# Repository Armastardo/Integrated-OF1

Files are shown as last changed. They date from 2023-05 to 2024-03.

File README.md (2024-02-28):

# Integrated-OF1
RaspberryPi Pico-powered board compatible with Rev 1 Heavy and Rev 1/2 Light cases (to be sold in waves on the Frame1.gg website).
  
<p align="center">
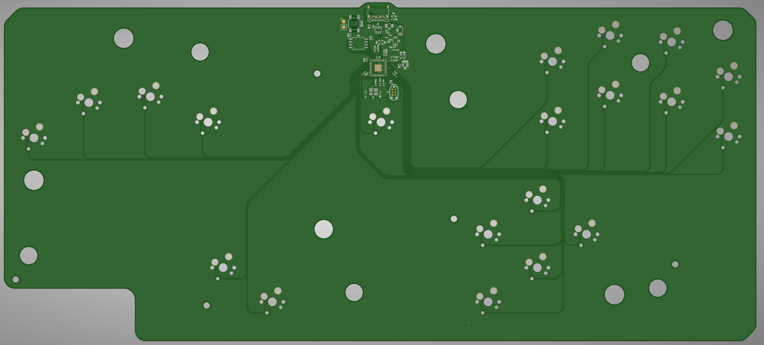
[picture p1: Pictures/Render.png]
  
</p>

Design files are available in this repository. Production files for JLCPCB in the releases page. Tested working and fitting previously mentioned Frame 1 cases.

## Table of contents
* [Features](#features)
* [Usage](#usage)
* [Acknowledgements](#acknowledgements)

## Features
- USB-C to GCC and USB-C to N64 cable compatible with integrated port.
- Uses [HayBox](https://github.com/JonnyHaystack/HayBox) and [Pico Rectangle](https://github.com/JulienBernard3383279/pico-rectangle) default pinout.

## Usage
1. Order via JLCPCB using the production files in the releases page.
2. Connect them to the PC and the first time it'll show up as a mass storage device.
3. Drop your prefered firmware in uf2 format and once it disconnects it should be good to go.
	- If you connect while pressing the BOOT button (or shorting the pads in the back), it'll show again as a mass storage device so you can update the firmware or replace it.
	- You can also press START on connect if using HayBox or CRIGHT if using pico-rectangle.

## Acknowledgements:
- Greg Turbo: For creating the Frame1 and the Open Frame 1.
- Crane's Lab discord server: For the community that inspired me to create things like this.

### Made using the Open Rectangle Template
OpenRectangleTemplate project - https://github.com/Armastardo/OpenRectangleTemplate

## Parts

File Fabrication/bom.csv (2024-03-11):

Designator | Footprint | Quantity | Value | LCSC Part #
C1, C10, C2, C4 | 0402 | 4 | 1uF | C52923
C11, C12, C13, C14, C15, C16, C17, C3, C5, C6 | 0402 | 10 | 100nF | C1525
C7, C8 | 0402 | 2 | 22pF | C1555
C9 | 0402 | 1 | 10uF | C15525
D1, D2 | D_SOD-123 | 2 | Schottky Diode | C8598
D3 | 0805 | 1 | GREEN | C2297
F1 | 1206 | 1 | 500 mA | C2836286
J1 | TYPE-C_24P_QCHT | 1 | USB C Connector | C456013
MX1, MX11, MX13, MX16, MX18, MX20, MX22, MX24, MX25, MX27, MX3, MX30, MX31, MX34, MX35, MX37, MX40, MX6, MX7, MX9 | SW_MX_HS_1u | 20 | MX_SW_HS
R1 | 0603 | 1 | 1M | C22935
R10, R11 | 0402 | 2 | 1k | C11702
R2, R3 | 0402 | 2 | 5.1k | C25905
R4 | 0402 | 1 | 470 | C25117
R5 | 0603 | 1 | 5.6k | C23189
R6 | 0603 | 1 | 10k | C25804
R7 | 0402 | 1 | 10k | C25744
R8, R9 | 0603 | 2 | 27 | C25190
SW1 | SW_SPST_SKQG_WithStem | 1 | Boot | C318884
U1 | SOT-23 | 1 | XC6206 | C5446
U2 | SOT-23-6 | 1 | USBLC6-2SC6 | C2827654
U3 | RP2040-QFN-56 | 1 | RP2040 | C2040
U4 | SOIC-8_5.23x5.23mm_P1.27mm | 1 | W25Q128JVS | C97521
Y1 | Crystal_SMD_3225-4Pin_3.2x2.5mm | 1 | 12MHz | C9002

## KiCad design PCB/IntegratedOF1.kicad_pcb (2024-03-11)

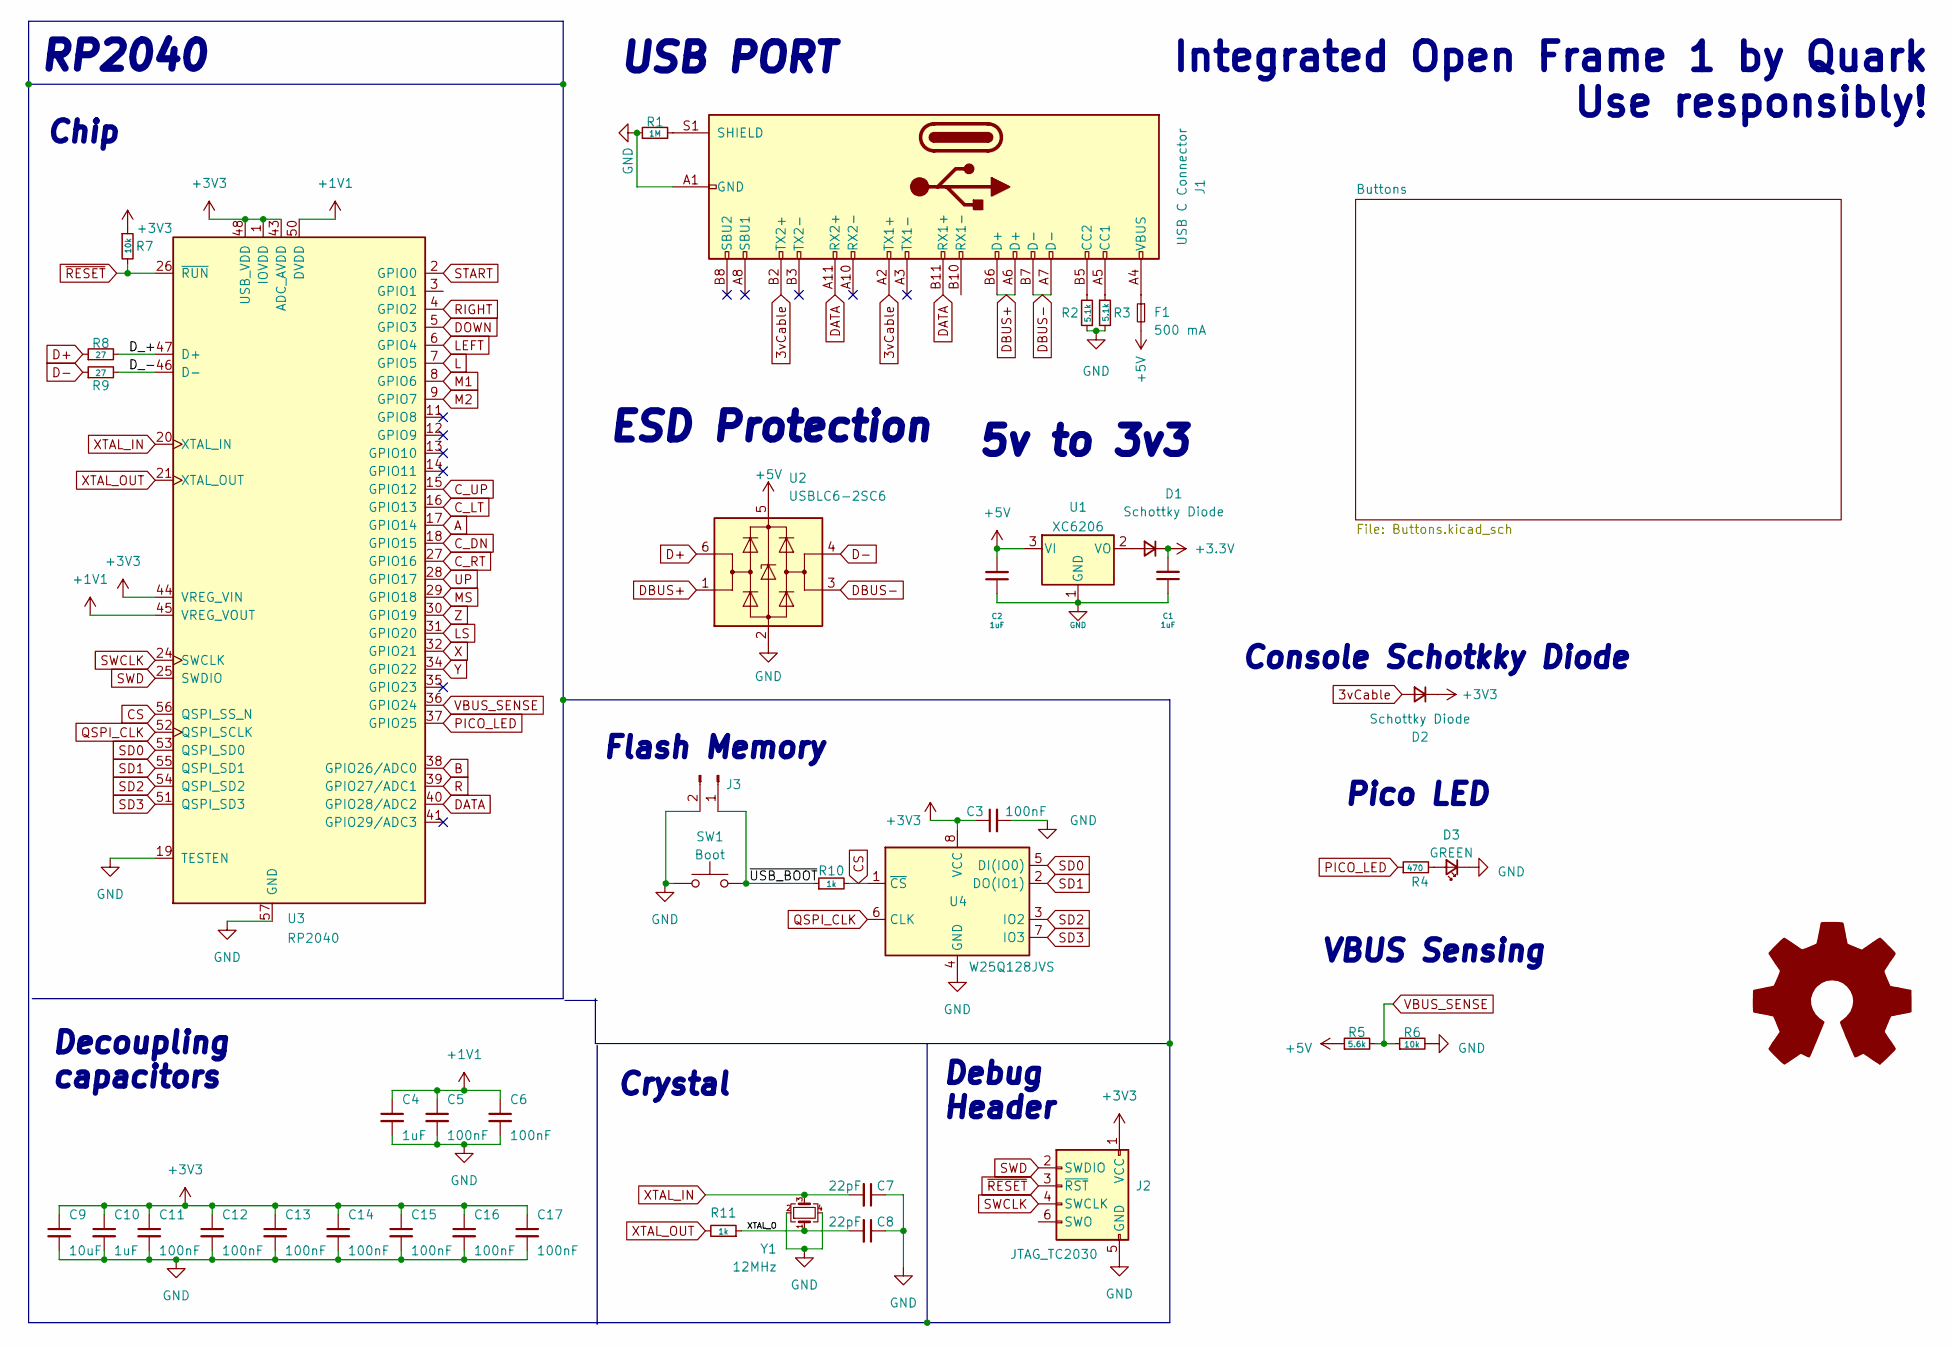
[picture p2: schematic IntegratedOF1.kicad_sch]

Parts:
C1, C2, C4, C10: 1uF; C_0402_1005Metric; LCSC C52923
C3, C5, C6, C11, C12, C13, C14, C15, C16, C17: 100nF; C_0402_1005Metric; LCSC C1525
C7, C8: 22pF; C_0402_1005Metric; LCSC C1555
C9: 10uF; C_0402_1005Metric; LCSC C15525
D1, D2: Schottky Diode; D_SOD-123; LCSC C8598
D3: GREEN; LED_0805_2012Metric; LCSC C2297
F1: 500 mA; Fuse_1206_3216Metric; LCSC C2836286
J1: USB C Connector; TYPE-C_24P_QCHT; LCSC C456013
J2: JTAG_TC2030; CON_TC2030_outlined
J3: Conn_01x02_Pin; PinHeader_1x02_P2.54mm_Vertical
R1: 1M; R_0603_1608Metric; LCSC C22935
R2, R3: 5.1k; R_0402_1005Metric; LCSC C25905
R4: 470; R_0402_1005Metric; LCSC C25117
R5: 5.6k; R_0603_1608Metric; LCSC C23189
R6: 10k; R_0603_1608Metric; LCSC C25804
R7: 10k; R_0402_1005Metric; LCSC C25744
R8, R9: 27; R_0603_1608Metric; LCSC C25190
R10, R11: 1k; R_0402_1005Metric; LCSC C11702
SW1: Boot; SW_SPST_SKQG_WithStem; LCSC C318884
SYM1: Logo_Open_Hardware_Large; OSHW-Logo_28.5x30mm_SilkScreen
U1: XC6206; SOT-23; LCSC C5446
U2: USBLC6-2SC6; SOT-23-6; LCSC C2827654
U3: RP2040; RP2040-QFN-56; LCSC C2040
U4: W25Q128JVS; SOIC-8_5.23x5.23mm_P1.27mm; LCSC C97521
Y1: 12MHz; Crystal_SMD_3225-4Pin_3.2x2.5mm; LCSC C9002

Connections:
3vCable: D2.2 (A), J1.A2 (TX1+), J1.B2 (TX2+)
+1V1: C4.1, C5.1, C6.1, U3.23 (DVDD), U3.45 (VREG_VOUT), U3.50 (DVDD)
+5V: C2.2, F1.2, R5.1, U1.3 (VI), U2.5 (VBUS)
/D_+: R8.2, U3.47 (D+)
/D_-: R9.2, U3.46 (D-)
/XTAL_O: C8.2, R11.1, Y1.1
/~USB_BOOT: J3.1, R10.1, SW1.2
A: U3.17 (GPIO14); also elsewhere on the board
B: U3.38 (GPIO26/ADC0); also elsewhere on the board
CS: R10.2, U3.56 (QSPI_SS_N), U4.1 (~CS)
C_DN: U3.18 (GPIO15); also elsewhere on the board
C_LT: U3.16 (GPIO13); also elsewhere on the board
C_RT: U3.27 (GPIO16); also elsewhere on the board
C_UP: U3.15 (GPIO12); also elsewhere on the board
D+: R8.1, U2.6 (I/O1)
D-: R9.1, U2.4 (I/O2)
DATA: J1.A11 (RX2+), J1.B11 (RX1+), U3.40 (GPIO28/ADC2)
DBUS+: J1.A6 (D+), J1.B6 (D+), U2.1 (I/O1)
DBUS-: J1.A7 (D-), J1.B7 (D-), U2.3 (I/O2)
DOWN: U3.5 (GPIO3); also elsewhere on the board
GND: C1.1, C2.1, C3.2, C4.2, C5.2, C6.2, C7.1, C8.1, C9.2, C10.2, C11.2, C12.2, C13.2, C14.2, C15.2, C16.2, C17.2, D3.1 (K), J1.A1 (GND), J1.A12 (GND), J1.B1 (GND), J1.B12 (GND), J2.5 (GND), J3.2, R1.1, R2.1, R3.2, R6.2, SW1.1, U1.1 (GND), U2.2 (GND), U3.19 (TESTEN), U3.57 (GND), U4.4 (GND), Y1.2, Y1.4; also elsewhere on the board
L: U3.7 (GPIO5); also elsewhere on the board
LEFT: U3.6 (GPIO4); also elsewhere on the board
LS: U3.31 (GPIO20); also elsewhere on the board
M1: U3.8 (GPIO6); also elsewhere on the board
M2: U3.9 (GPIO7); also elsewhere on the board
MS: U3.29 (GPIO18); also elsewhere on the board
unnamed: D1.2 (A), U1.2 (VO)
unnamed: D3.2 (A), R4.2
unnamed: F1.1, J1.A4 (VBUS), J1.A9 (VBUS), J1.B4 (VBUS), J1.B9 (VBUS)
unnamed: J1.A5 (CC1), R3.1
unnamed: J1.B5 (CC2), R2.2
unnamed: J1.S1 (SHIELD), R1.2
PICO_LED: R4.1, U3.37 (GPIO25)
QSPI_CLK: U3.52 (QSPI_SCLK), U4.6 (CLK)
R: U3.39 (GPIO27/ADC1); also elsewhere on the board
RIGHT: U3.4 (GPIO2); also elsewhere on the board
SD0: U3.53 (QSPI_SD0), U4.5 (DI(IO0))
SD1: U3.55 (QSPI_SD1), U4.2 (DO(IO1))
SD2: U3.54 (QSPI_SD2), U4.3 (IO2)
SD3: U3.51 (QSPI_SD3), U4.7 (IO3)
START: U3.2 (GPIO0); also elsewhere on the board
SWCLK: J2.4 (SWCLK), U3.24 (SWCLK)
SWD: J2.2 (SWDIO), U3.25 (SWDIO)
UP: U3.28 (GPIO17); also elsewhere on the board
VBUS_SENSE: R5.2, R6.1, U3.36 (GPIO24)
X: U3.32 (GPIO21); also elsewhere on the board
XTAL_IN: C7.2, U3.20 (XTAL_IN), Y1.3
XTAL_OUT: R11.2, U3.21 (XTAL_OUT)
Y: U3.34 (GPIO22); also elsewhere on the board
Z: U3.30 (GPIO19); also elsewhere on the board
~RESET: J2.3 (~RST), R7.2, U3.26 (~RUN)

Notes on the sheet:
Integrated Open Frame 1 by Quark Use responsibly!
5v to 3v3
ESD Protection
RP2040
Console Schotkky Diode
USB PORT
Flash Memory
Debug Header
Pico LED
VBUS Sensing
Chip
Decoupling capacitors
Crystal

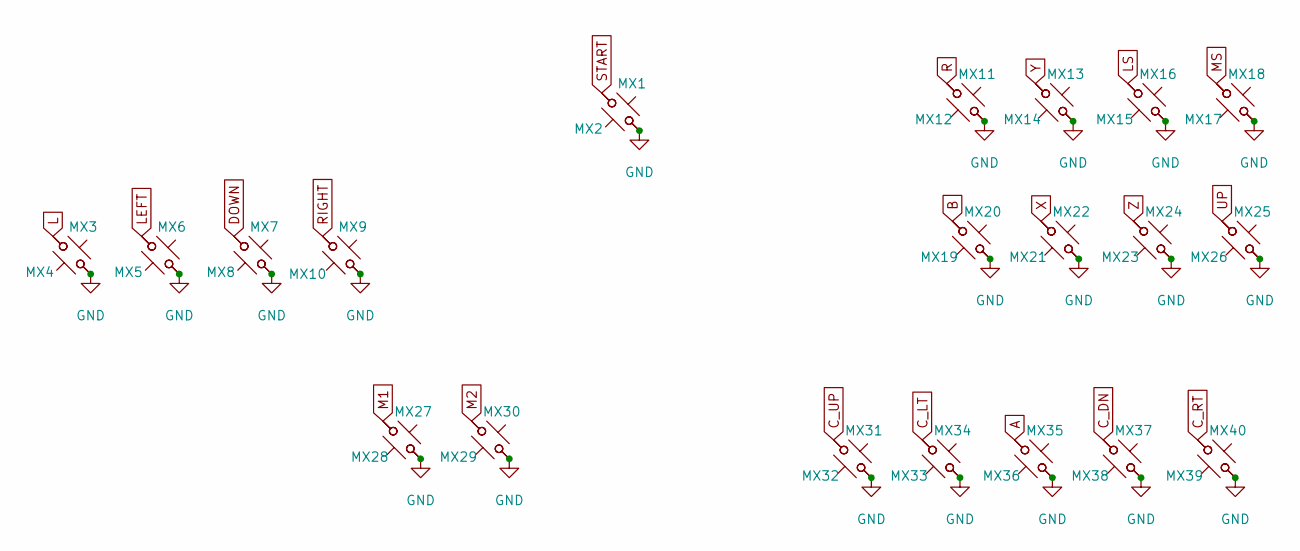
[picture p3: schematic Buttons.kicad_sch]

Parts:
MX1, MX3, MX6, MX7, MX9, MX11, MX13, MX16, MX18, MX20, MX22, MX24, MX25, MX27, MX30, MX31, MX34, MX35, MX37, MX40: MX_SW_HS; SW_MX_HS_1u
MX2, MX4, MX5, MX8, MX10, MX12, MX14, MX15, MX17, MX19, MX21, MX23, MX26, MX28, MX29, MX32, MX33, MX36, MX38, MX39: MX_SW_solder; SW_MX_1u

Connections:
A: MX35.1, MX36.2; also elsewhere on the board
B: MX19.2, MX20.1; also elsewhere on the board
C_DN: MX37.1, MX38.2; also elsewhere on the board
C_LT: MX33.2, MX34.1; also elsewhere on the board
C_RT: MX39.2, MX40.1; also elsewhere on the board
C_UP: MX31.1, MX32.2; also elsewhere on the board
DOWN: MX7.1, MX8.2; also elsewhere on the board
GND: MX1.2, MX2.1, MX3.2, MX4.1, MX5.1, MX6.2, MX7.2, MX8.1, MX9.2, MX10.1, MX11.2, MX12.1, MX13.2, MX14.1, MX15.1, MX16.2, MX17.1, MX18.2, MX19.1, MX20.2, MX21.1, MX22.2, MX23.1, MX24.2, MX25.2, MX26.1, MX27.2, MX28.1, MX29.1, MX30.2, MX31.2, MX32.1, MX33.1, MX34.2, MX35.2, MX36.1, MX37.2, MX38.1, MX39.1, MX40.2; also elsewhere on the board
L: MX3.1, MX4.2; also elsewhere on the board
LEFT: MX5.2, MX6.1; also elsewhere on the board
LS: MX15.2, MX16.1; also elsewhere on the board
M1: MX27.1, MX28.2; also elsewhere on the board
M2: MX29.2, MX30.1; also elsewhere on the board
MS: MX17.2, MX18.1; also elsewhere on the board
R: MX11.1, MX12.2; also elsewhere on the board
RIGHT: MX9.1, MX10.2; also elsewhere on the board
START: MX1.1, MX2.2; also elsewhere on the board
UP: MX25.1, MX26.2; also elsewhere on the board
X: MX21.2, MX22.1; also elsewhere on the board
Y: MX13.1, MX14.2; also elsewhere on the board
Z: MX23.2, MX24.1; also elsewhere on the board

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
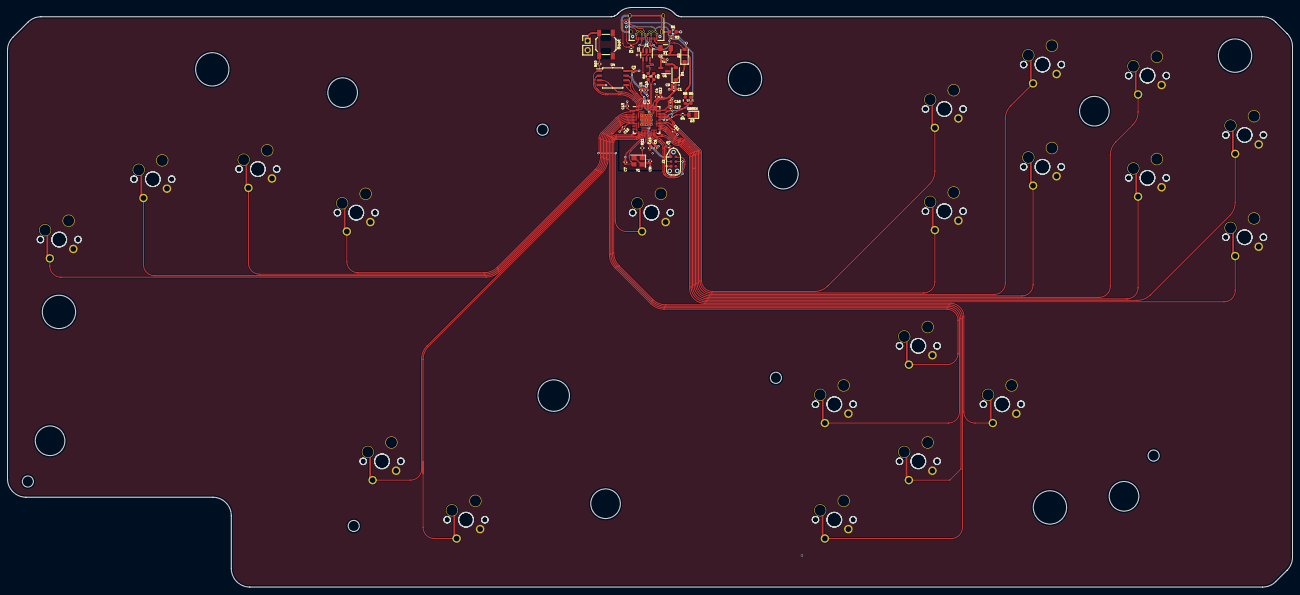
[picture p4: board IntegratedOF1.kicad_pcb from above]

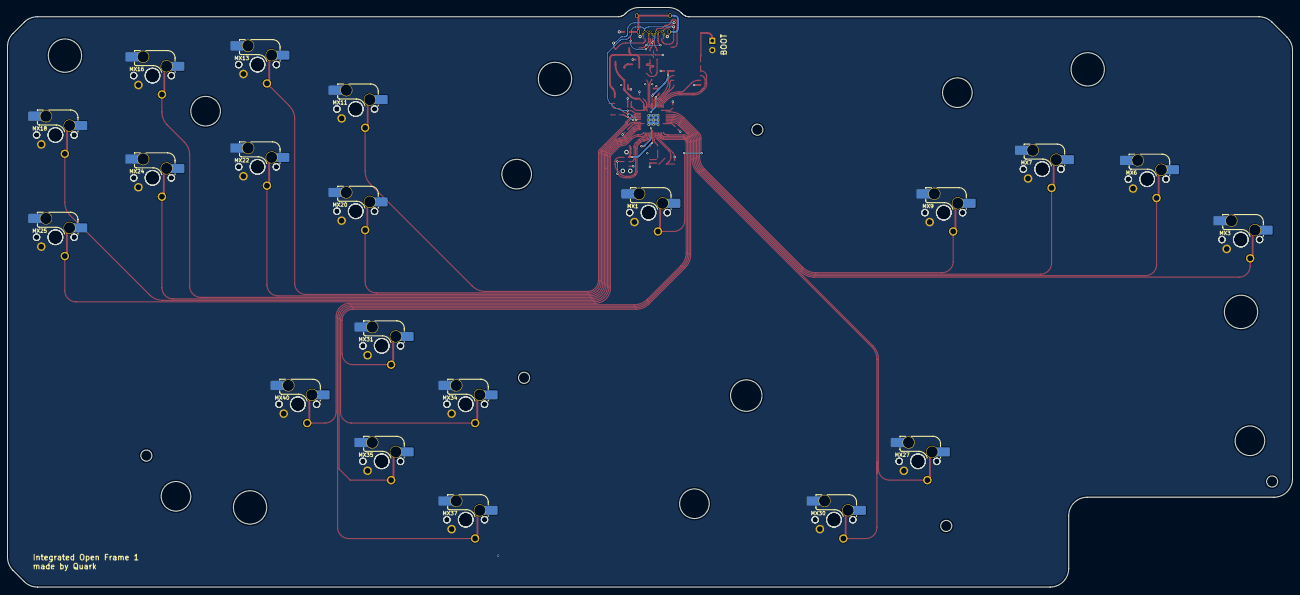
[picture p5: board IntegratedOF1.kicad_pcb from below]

Board: 2 copper layers, 347.0 x 156.5 mm, 81 parts (20 on the bottom side), 53 nets.

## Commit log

2023-05-22 Initial commit, done.
    [Buttons.kicad_sch, IntegratedOF1.kicad_pcb, IntegratedOF1.kicad_sch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]
2023-05-22 Adjusted BOM and Readme.md
    Added a part number for the BOOT button, added Acknowledgements section. Fixed a typo
    [bom.csv]
2023-05-22 Adjusted PCB and BOM
    - Adjusted PCB to add missing screw hole and repositioned one more according to the plate file.
    - Move the shield resistor to a new position where it shouldn't interfere with some cases.
    - Added a new cutout in the PCB so it's easier to extract from a F1 case.
    - Changed Schottky diode and boot button part # so they use a basic part instead of an extended one.
    [IntegratedOF1.kicad_pcb, IntegratedOF1.kicad_sch, bom.csv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]
2024-03-11 Adjusted push button to the correct part number
    [IntegratedOF1.kicad_pcb, IntegratedOF1.kicad_sch, bom.csv]
